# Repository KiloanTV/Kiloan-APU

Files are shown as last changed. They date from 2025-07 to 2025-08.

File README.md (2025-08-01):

<div>
  <h1 align="center">Kiloan APU V1</h1>

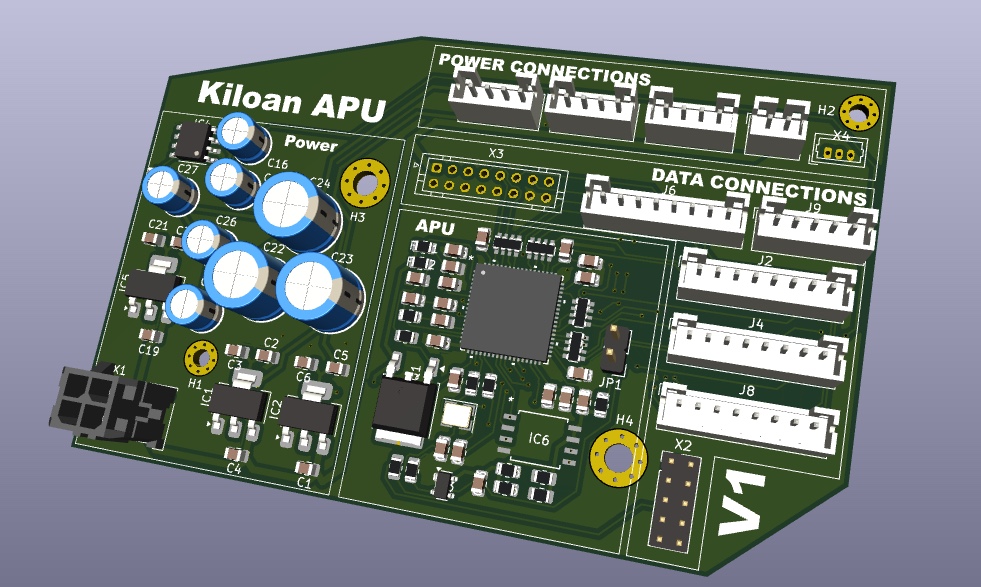
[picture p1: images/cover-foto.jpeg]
Kiloan-APU
  

  <p align="center">
  <a href="https://hackclub.com/highway">
    
  </a>
  </p>
  <h1></h1>
  <p align="center">
    The mainboard for a custom digital mixing console!
  </p>
</div>

<sub align="center">This work is licensed under the
[MIT License](https://mit-license.org).
</sub>

## Table of Contents

- [About](#about)
- [Pictures](#pictures)
- [Bill of Materials](#bill-of-materials)

# About

I've always wanted my own digital mixing console, but those things are just too expensive for teenagers. That's why I want to build my own! This is the mainboard, to which additional PCB boards will later be attached. They provide inputs/outputs (balanced XLR, of course), are responsible for the controls, and serve as a USB audio interface. This is the first step in this extensive project!

# Pictures

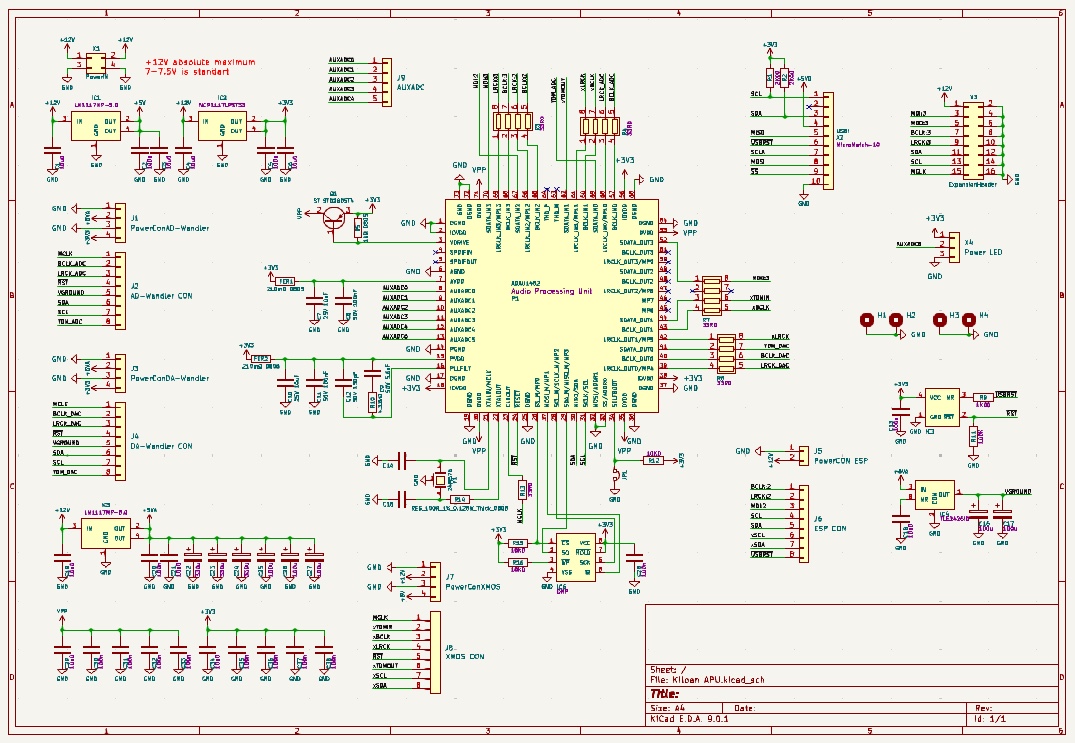
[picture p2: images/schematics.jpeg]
schematics


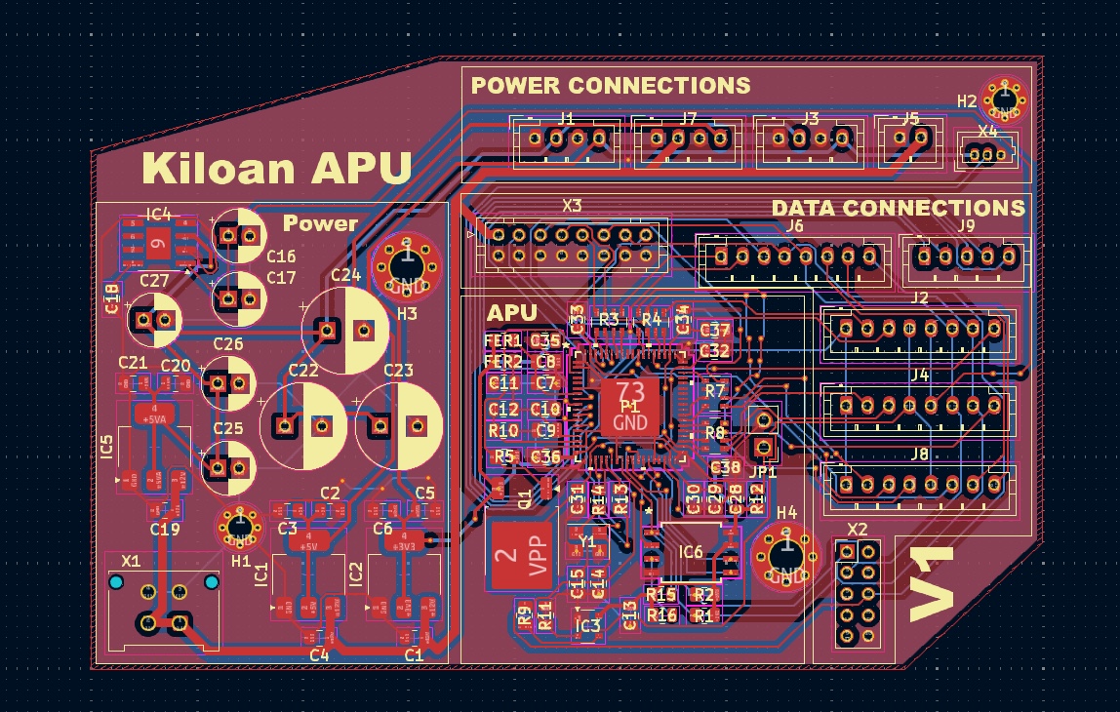
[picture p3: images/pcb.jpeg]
pcb


# Bill of Materials

|Reference |Value |Description |Qty|LCSC |Price|FIELD7 |
|---|---|---|---|---|-----|---|
|C1 |25V 10u0 | |1  |C391262 | | |
|C2,C5,C13,C20,C28,C30,C31,C32,C33,C35,C36,C37,C38|CAP_100n_50V_X7R_0805 | |13 |C3018562 | | |
|C3,C4,C6,C18,C19,C21,C29,C34 |CAP_10u0_25V_X5R_0805 | |8  |C391262 | | |
|C7,C10 |25V 10uF |25V 10uF X5R ±20% 0805 Multilayer Ceramic Capacitors MLCC - SMD/SMT ROHS |2  |C391262 | | |
|C8,C11 |50V 100nF |50V 100nF X7R ±10% 0805 Multilayer Ceramic Capacitors MLCC - SMD/SMT ROHS |2  |C3018562 | | |
|C9 |50V 5.6nF |50V 5.6nF X7R ±10% 0805 Multilayer Ceramic Capacitors MLCC - SMD/SMT ROHS |1  |C113862 | | |
|C12 |50V 150pF |50V 150pF C0G ±5% 0805 Multilayer Ceramic Capacitors MLCC - SMD/SMT ROHS |1  |C2168780 | | |
|C14,C15 |50V 12pF | |2  |C2168859 | | |
|C16,C17,C25,C26,C27 |CAP_100u_20%_25V_ALUM_RADIAL | |5  |C108360,C136287| | |
|C22,C23,C24 |330u_20%_25V_ALUM_RADIAL | |3  |C47344178 | | |
|FER1,FER2 |210mΩ 0805 |210mΩ ±25% 600Ω@100MHz 0805 Ferrite Beads ROHS |2  |C85837 | | |
|IC1,IC5 |IC_LM1117MP-5.0 | |2  |C131933 | | |
|IC2 |IC_NCP1117LPST33 | |1  |C146799 | | |
|IC3 |IC_ADM811TARTZ | |1  |C462205 | | |
|IC4 |IC_TLE2426ID | |1  |C59459 | | |
|IC6 |IC_25AA1024 | |1  |C2653525 | | |
|J1 |PowerConAD-Wandler |Generic connector, single row, 01x04, script generated (kicad-library-utils/schlib/autogen/connector/) |1  |C131334 | | |
|J2 |AD-Wandler CON |Generic connector, single row, 01x08, script generated (kicad-library-utils/schlib/autogen/connector/) |1  |C157974 | | |
|J3 |PowerConDA-Wandler |Generic connector, single row, 01x04, script generated (kicad-library-utils/schlib/autogen/connector/) |1  |C131334 | | |
|J4 |DA-Wandler CON |Generic connector, single row, 01x08, script generated (kicad-library-utils/schlib/autogen/connector/) |1  |C157974 | | |
|J5 |PowerCON ESP |Generic connector, single row, 01x02, script generated (kicad-library-utils/schlib/autogen/connector/) |1  |C131337 | | |
|J6 |ESP CON |Generic connector, single row, 01x08, script generated (kicad-library-utils/schlib/autogen/connector/) |1  |C157974 | | |
|J7 |PowerConXMOS |Generic connector, single row, 01x04, script generated (kicad-library-utils/schlib/autogen/connector/) |1  |C131334 | | |
|J8 |XMOS CON |Generic connector, single row, 01x08, script generated (kicad-library-utils/schlib/autogen/connector/) |1  |C157974 | | |
|J9 |AUXADC |Generic connector, single row, 01x05, script generated (kicad-library-utils/schlib/autogen/connector/) |1  |C157993 | | |
|JP1 |CON_JUMPER | |1  |C492401 | | |
|P1 |ADAU1452 |Audio Processing Unit |1  |C462188 | | |
|Q1 |ST STD2805T4 |PNP 60V 5A 150MHz 15W |1  |C672201 | | |
|R1,R2 |RES_2K00_1%_0.125W_Thick_0805| |2  |C114572 | | |
|R3,R4,R7,R8 |33R0_5%_4x0603 | |4  |C872331 | | |
|R5 |1kΩ 0805 |125mW Thick Film Resistor 150V ±100ppm/℃ ±1% 1kΩ 0805 Chip Resistor - Surface Mount ROHS |1  |C95781 | | |
|R9 |RES_1K00_1%_0.125W_Thick_0805| |1  |C95781 | | |
|R10 |4.32kΩ |125mW Thick Film Resistor 150V ±100ppm/℃ ±1% 4.32kΩ 0805 Chip Resistor - Surface Mount ROHS |1  |C483139 | | |
|R11 |RES_100K_1%_0.125W_Thick_0805| |1  |C96346 | | |
|R12,R15,R16 |RES_10K0_1%_0.125W_Thick_0805| |3  |C84376 | | |
|R13 |RES_33R0_1%_0.125W_Thick_0805| |1  |C126353 | | |
|R14 |RES_100R_1%_0.125W_Thick_0805| |1  |C105577 | | |
|X1 |PowerIN |2x2P 4P Micro-Fit(MX 3.0) Tin 3mm 2 -40℃~+105℃ 8.5A 2 3mm Brass Through Hole Through Hole,P=3mm Wire To Board Connector ROHS|1  |C277721 | | |
|X2 |USBi | |1  |C18723067 | | |
|X3 |ExpansionHeader | |1  |C3324391 | | |
|X4 |Power LED |Generic connector, single row, 01x03, script generated (kicad-library-utils/schlib/autogen/connector/) |1  |C122442 | | |
|Y1 |24M576 | |1  |C6040680 | | |
| | | | | | |Quote from LCSC: $27,07|
| | | | | | |Quote from JLCPCB: 4.17 USD|
| | | | | | |Quote Total: 31.24 USD|

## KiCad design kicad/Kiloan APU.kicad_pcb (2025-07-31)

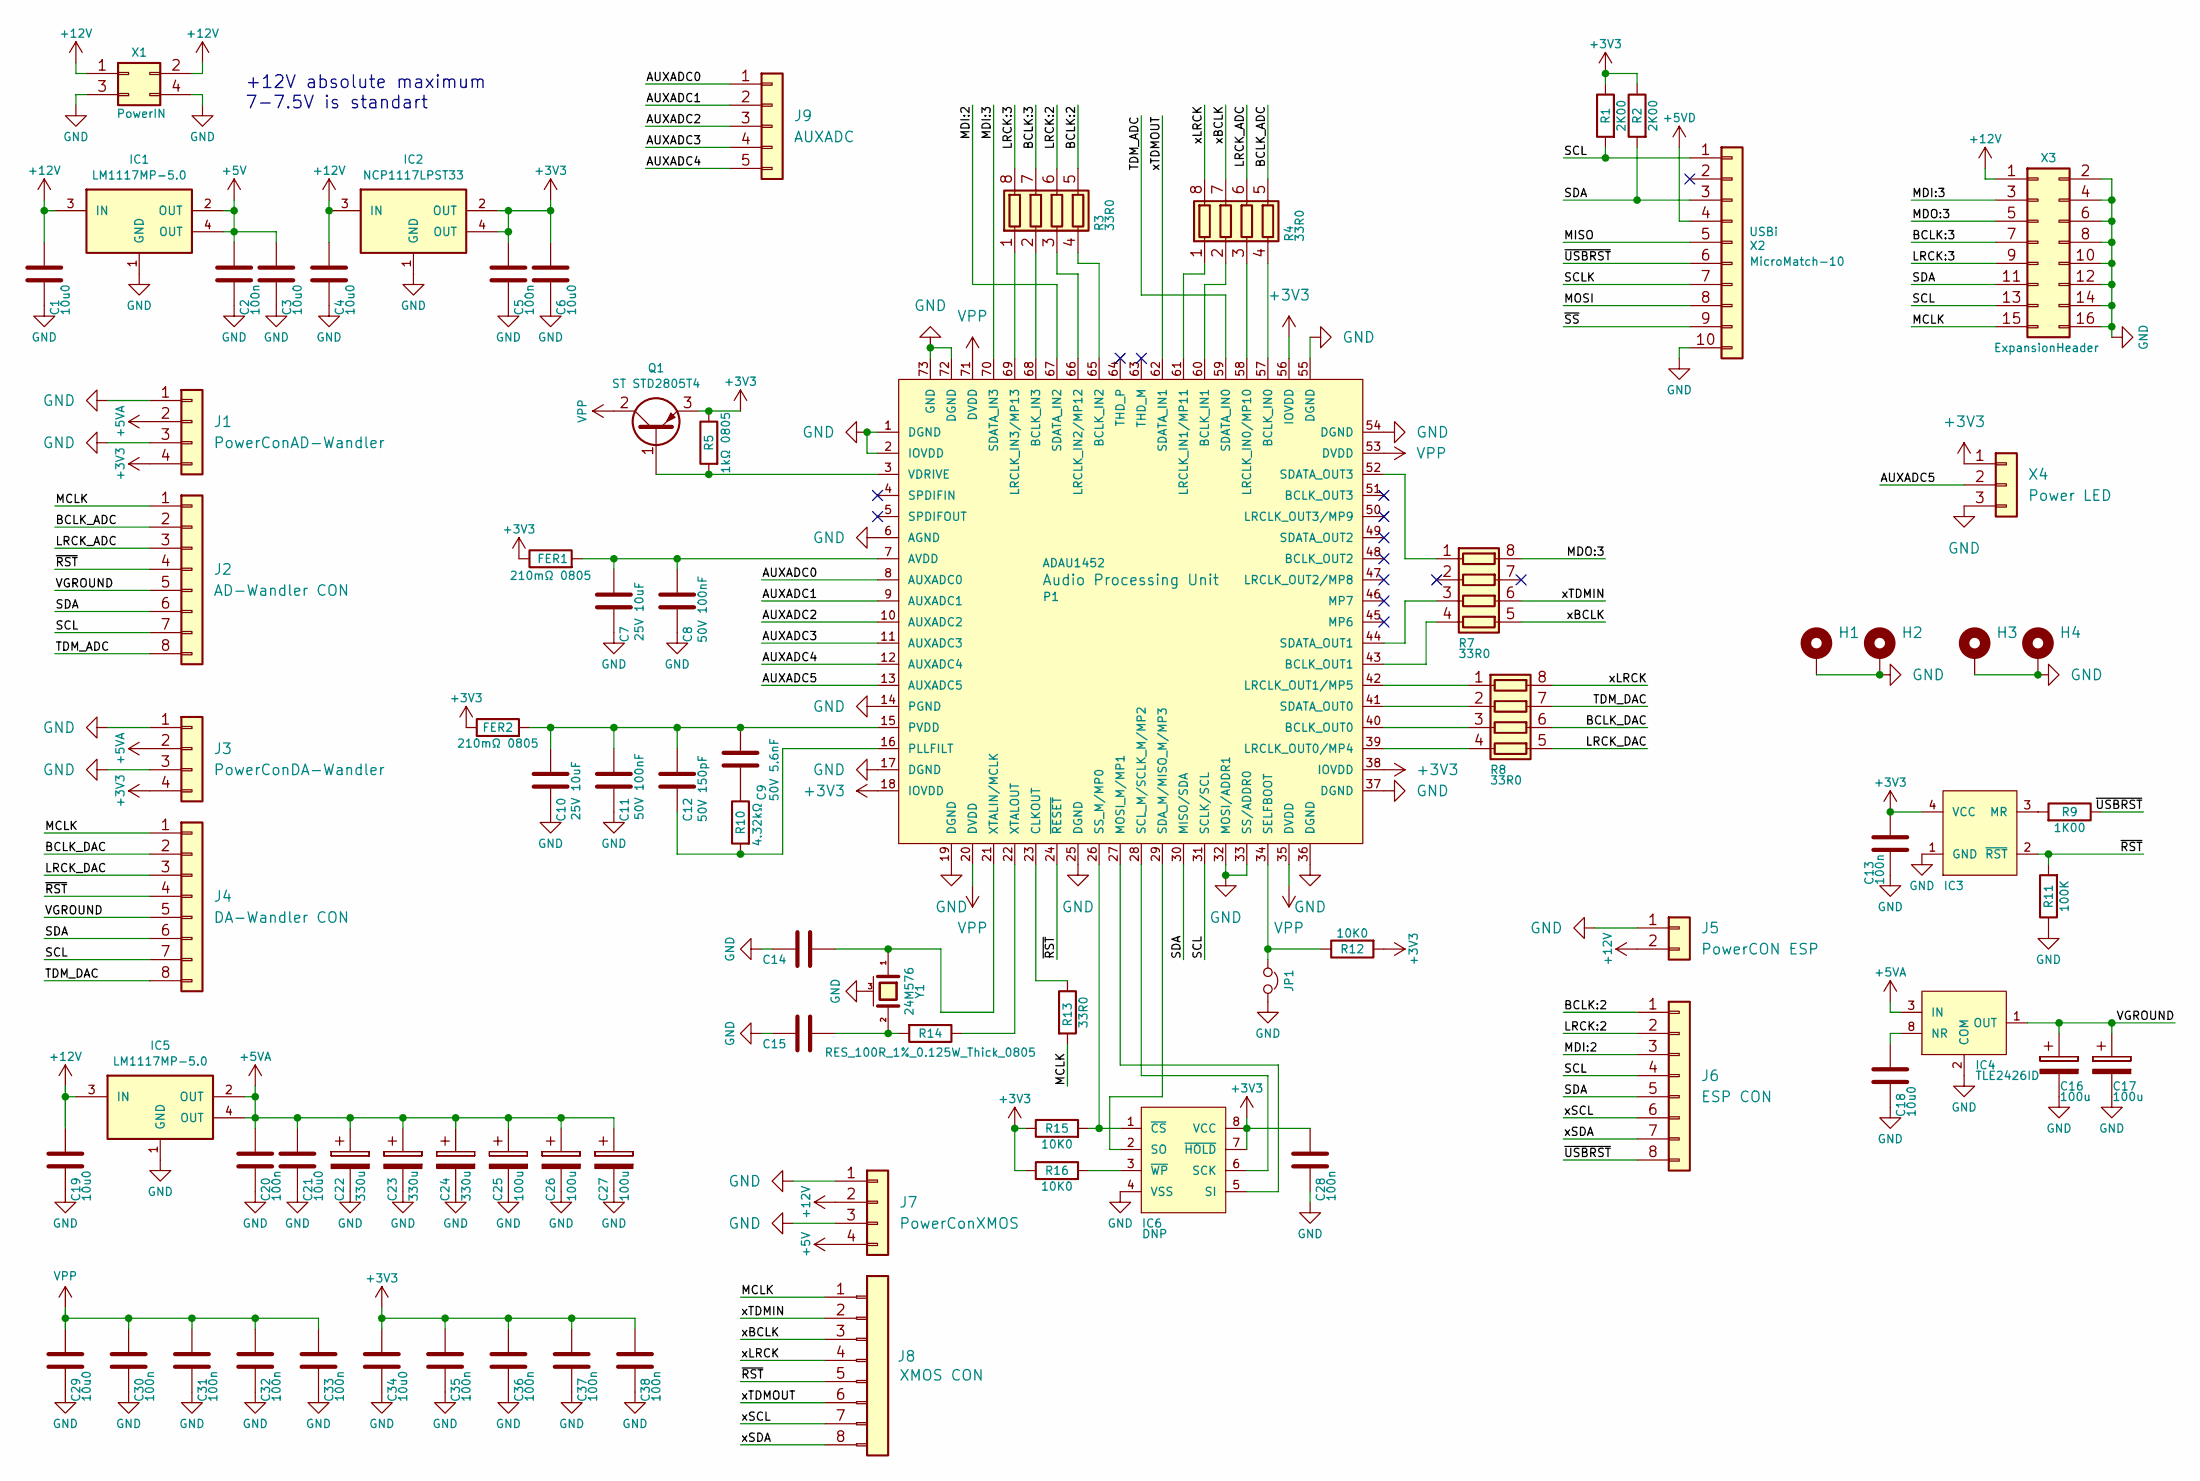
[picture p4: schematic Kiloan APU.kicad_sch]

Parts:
C1: 25V 10u0; C_0805_2012Metric; LCSC C391262
C2, C5, C13, C20, C28, C30, C31, C32, C33, C35, C36, C37, C38: CAP_100n_50V_X7R_0805; C_0805_2012Metric; LCSC C3018562
C3, C4, C6, C18, C19, C21, C29, C34: CAP_10u0_25V_X5R_0805; C_0805_2012Metric; LCSC C391262
C7, C10: 25V 10uF; C_0805_2012Metric; Part Number GRM21BR61E106MA73L; LCSC C391262
C8, C11: 50V 100nF; C_0805_2012Metric; Part Number C0805C104K5RACTU; LCSC C3018562
C9: 50V 5.6nF; C_0805_2012Metric; Part Number CC0805KRX7R9BB562; LCSC C113862
C12: 50V 150pF; C_0805_2012Metric; Part Number C0805C151J5GACTU; LCSC C2168780
C14, C15: 50V 12pF; C_0805_2012Metric; Part Number C0805C220J5GACTU; LCSC C2168859
C16, C17: CAP_100u_20%_25V_ALUM_RADIAL; CP_Radial_D5.0mm_P2.00mm; LCSC C136287
C22, C23, C24: 330u_20%_25V_ALUM_RADIAL; CP_Radial_D8.0mm_P3.50mm; LCSC C47344178
C25, C26, C27: CAP_100u_20%_25V_ALUM_RADIAL; CP_Radial_D5.0mm_P2.00mm; LCSC C108360
FER1, FER2: 210mΩ 0805; R_0805_2012Metric; Part Number BLM21AG601SN1D; LCSC C85837
H1, H2: MountingHole_Pad; MountingHole_2.2mm_M2_Pad_Via
H3, H4: MountingHole_Pad; MountingHole_3.2mm_M3_Pad_Via
IC1, IC5: IC_LM1117MP-5.0; SOT-223; LCSC C131933
IC2: IC_NCP1117LPST33; SOT-223; LCSC C146799
IC3: IC_ADM811TARTZ; SOT-143; Part Number ADM811TARTZ-REEL; LCSC C462205
IC4: IC_TLE2426ID; SOIC-8-1EP_3.9x4.9mm_P1.27mm_EP2.29x3mm; LCSC C59459
IC6: IC_25AA1024; SOIJ8-M_MC_MCH; LCSC C2653525
J1: PowerConAD-Wandler; JST_PH_B4B-PH-K_1x04_P2.00mm_Vertical; LCSC C131334
J2: AD-Wandler CON; JST_PH_B8B-PH-K_1x08_P2.00mm_Vertical; LCSC C157974
J3: PowerConDA-Wandler; JST_PH_B4B-PH-K_1x04_P2.00mm_Vertical; LCSC C131334
J4: DA-Wandler CON; JST_PH_B8B-PH-K_1x08_P2.00mm_Vertical; LCSC C157974
J5: PowerCON ESP; JST_PH_B2B-PH-K_1x02_P2.00mm_Vertical; LCSC C131337
J6: ESP CON; JST_PH_B8B-PH-K_1x08_P2.00mm_Vertical; LCSC C157974
J7: PowerConXMOS; JST_PH_B4B-PH-K_1x04_P2.00mm_Vertical; LCSC C131334
J8: XMOS CON; JST_PH_B8B-PH-K_1x08_P2.00mm_Vertical; LCSC C157974
J9: AUXADC; JST_PH_B5B-PH-K_1x05_P2.00mm_Vertical; LCSC C157993
JP1: CON_JUMPER; PinHeader_1x02_P2.54mm_Vertical; LCSC C492401
P1: ADAU1452; CP-72-6_ADI-M; Part Number ADAU1452WBCPZ-RL; LCSC C462188
Q1: ST STD2805T4; TO-252-2; Part Number STD2805T4; LCSC C672201
R1, R2: RES_2K00_1%_0.125W_Thick_0805; R_0805_2012Metric; LCSC C114572
R3, R4, R7, R8: 33R0_5%_4x0603; R_Array_Convex_4x0603; LCSC C872331
R5: 1kΩ 0805; R_0805_2012Metric; Part Number RC0805FR-071KL; LCSC C95781
R9: RES_1K00_1%_0.125W_Thick_0805; R_0805_2012Metric; LCSC C95781
R10: 4.32kΩ; R_0805_2012Metric; Part Number RC0805FR-074K32L; LCSC C483139
R11: RES_100K_1%_0.125W_Thick_0805; R_0805_2012Metric; LCSC C96346
R12, R15, R16: RES_10K0_1%_0.125W_Thick_0805; R_0805_2012Metric; LCSC C84376
R13: RES_33R0_1%_0.125W_Thick_0805; R_0805_2012Metric; LCSC C126353
R14: RES_100R_1%_0.125W_Thick_0805; R_0805_2012Metric; LCSC C105577
X1: PowerIN; Molex_Micro-Fit_3.0_43045-0412_2x02_P3.00mm_Vertical; Part Number 430450412; LCSC C277721
X2: USBi; PinHeader_2x05_P2.00mm_Vertical; LCSC C18723067
X3: ExpansionHeader; JST_PHD_B16B-PHDSS_2x08_P2.00mm_Vertical; LCSC C3324391
X4: Power LED; Molex_PicoBlade_53047-0310_1x03_P1.25mm_Vertical; LCSC C122442
Y1: 24M576; Crystal_SMD_3225-4Pin_3.2x2.5mm; LCSC C6040680

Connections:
+3V3: C5.1, C6.1, C13.1, C28.1, C34.1, C35.1, C36.1, C37.1, C38.1, FER1.1, FER2.1, IC2.2 (OUT), IC2.4 (OUT), IC3.4 (VCC), IC6.7 (~HOLD), IC6.8 (VCC), J1.4 (3V3), J3.4 (3V3), P1.18 (IOVDD), P1.38 (IOVDD), P1.56 (IOVDD), Q1.3 (E), R1.1, R2.1, R5.1, R12.2, R15.1, R16.1, X4.1
+5V: C2.1, C3.1, IC1.2 (OUT), IC1.4 (OUT), J7.4 (5V)
+5VA: C20.1, C21.1, C22.1, C23.1, C24.1, C25.1, C26.1, C27.1, IC4.3 (IN), IC5.2 (OUT), IC5.4 (OUT), J1.2 (5VA), J3.2 (5VA)
+5VD: X2.4
+12V: C1.1, C4.1, C19.1, IC1.3 (IN), IC2.3 (IN), IC5.3 (IN), J5.2 (12V), J7.2 (12V), X1.1, X1.2, X3.1
/AUXADC0: J9.1, P1.8 (AUXADC0)
/AUXADC1: J9.2, P1.9 (AUXADC1)
/AUXADC2: J9.3, P1.10 (AUXADC2)
/AUXADC3: J9.4, P1.11 (AUXADC3)
/AUXADC4: J9.5, P1.12 (AUXADC4)
/AUXADC5: P1.13 (AUXADC5), X4.2
/BCLK:2: J6.1 (BCLK), R3.5 (R4.2)
/BCLK:3: R3.7 (R2.2), X3.7
/BCLK_ADC: J2.2 (BCLK), R4.5 (R4.2)
/BCLK_DAC: J4.2 (BCLK), R8.6 (R3.2)
/LRCK:2: J6.2 (LRCK), R3.6 (R3.2)
/LRCK:3: R3.8 (R1.2), X3.9
/LRCK_ADC: J2.3 (LRCK), R4.6 (R3.2)
/LRCK_DAC: J4.3 (LRCK), R8.5 (R4.2)
/MCLK: J2.1 (MCLK), J4.1 (MCLK), J8.1 (MCLK), R13.2, X3.15
/MDI:2: J6.3 (SDATA), P1.67 (SDATA_IN2)
/MDI:3: P1.70 (SDATA_IN3), X3.3
/MDO:3: R7.8 (R1.2), X3.5
/MISO: X2.5
/MOSI: X2.8
/SCL: J2.7 (SCL), J4.7 (SCL), J6.4 (SCL1), P1.31 (SCLK/SCL), R1.2, X2.1, X3.13
/SCLK: X2.7
/SDA: J2.6 (SDA), J4.6 (SDA), J6.5 (SDA1), P1.30 (MISO/SDA), R2.2, X2.3, X3.11
/TDM_ADC: J2.8 (TDM), P1.59 (SDATA_IN0)
/TDM_DAC: J4.8 (TDM), R8.7 (R2.2)
/VGROUND: C16.1, C17.1, IC4.1 (OUT), J2.5 (VGROUND), J4.5 (VGROUND)
/xBCLK: J8.3 (XBCLK), R4.7 (R2.2), R7.5 (R4.2)
/xLRCK: J8.4 (XLRCK), R4.8 (R1.2), R8.8 (R1.2)
/xSCL: J6.6 (SCL2), J8.7 (SCL)
/xSDA: J6.7 (SDA2), J8.8 (SDA)
/xTDMIN: J8.2 (XTDMIN1), R7.6 (R3.2)
/xTDMOUT: J8.6 (XTDMOUT1), P1.62 (SDATA_IN1)
/~RST: IC3.2 (~RST), J2.4 (RST), J4.4 (RST), J8.5 (RST), P1.24 (~RESET), R11.2
/~SS: X2.9
/~USBRST: J6.8 (MRST), R9.1, X2.6
GND: C1.2, C2.2, C3.2, C4.2, C5.2, C6.2, C7.2, C8.2, C10.2, C11.2, C13.2, C14.2, C15.2, C16.2, C17.2, C18.2, C19.2, C20.2, C21.2, C22.2, C23.2, C24.2, C25.2, C26.2, C27.2, C28.2, C29.2, C30.2, C31.2, C32.2, C33.2, C34.2, C35.2, C36.2, C37.2, C38.2, H1.1, H2.1, H3.1, H4.1, IC1.1 (GND), IC2.1 (GND), IC3.1 (GND), IC4.2 (COM), IC5.1 (GND), IC6.4 (VSS), J1.1 (GND), J1.3 (GND), J3.1 (GND), J3.3 (GND), J5.1 (GND), J7.1 (GND), J7.3 (GND), JP1.2, P1.1 (DGND), P1.2 (IOVDD), P1.6 (AGND), P1.14 (PGND), P1.17 (DGND), P1.19 (DGND), P1.25 (DGND), P1.32 (MOSI/ADDR1), P1.33 (SS/ADDR0), P1.36 (DGND), P1.37 (DGND), P1.54 (DGND), P1.55 (DGND), P1.72 (DGND), P1.73 (GND), R11.1, X1.3, X1.4, X2.10, X3.2, X3.4, X3.6, X3.8, X3.10, X3.12, X3.14, X3.16, X4.3, Y1.3 (case)
unnamed: C9.2, R10.1
unnamed: C15.1, R14.2, Y1.2
unnamed: IC3.3 (MR), R9.2
unnamed: C18.1, IC4.8 (NR)
unnamed: IC6.6 (SCK), P1.28 (SCL_M/SCLK_M/MP2)
unnamed: IC6.5 (SI), P1.27 (MOSI_M/MP1)
unnamed: IC6.2 (SO), P1.29 (SDA_M/MISO_M/MP3)
unnamed: IC6.1 (~CS), P1.26 (SS_M/MP0), R15.2
unnamed: IC6.3 (~WP), R16.2
unnamed: C7.1, C8.1, FER1.2, P1.7 (AVDD)
unnamed: P1.57 (BCLK_IN0), R4.4 (R4.1)
unnamed: P1.60 (BCLK_IN1), R4.2 (R2.1)
unnamed: P1.65 (BCLK_IN2), R3.4 (R4.1)
unnamed: P1.68 (BCLK_IN3), R3.2 (R2.1)
unnamed: P1.40 (BCLK_OUT0), R8.3 (R3.1)
unnamed: P1.43 (BCLK_OUT1), R7.4 (R4.1)
unnamed: P1.23 (CLKOUT), R13.1
unnamed: P1.58 (LRCLK_IN0/MP10), R4.3 (R3.1)
unnamed: P1.61 (LRCLK_IN1/MP11), R4.1 (R1.1)
unnamed: P1.66 (LRCLK_IN2/MP12), R3.3 (R3.1)
unnamed: P1.69 (LRCLK_IN3/MP13), R3.1 (R1.1)
unnamed: P1.39 (LRCLK_OUT0/MP4), R8.4 (R4.1)
unnamed: P1.42 (LRCLK_OUT1/MP5), R8.1 (R1.1)
unnamed: C12.2, P1.16 (PLLFILT), R10.2
unnamed: C9.1, C10.1, C11.1, C12.1, FER2.2, P1.15 (PVDD)
unnamed: P1.41 (SDATA_OUT0), R8.2 (R2.1)
unnamed: P1.44 (SDATA_OUT1), R7.3 (R3.1)
unnamed: P1.52 (SDATA_OUT3), R7.1 (R1.1)
unnamed: JP1.1, P1.34 (SELFBOOT), R12.1
unnamed: P1.3 (VDRIVE), Q1.1 (B), R5.2
unnamed: C14.1, P1.21 (XTALIN/MCLK), Y1.1
unnamed: P1.22 (XTALOUT), R14.1
VPP: C29.1, C30.1, C31.1, C32.1, C33.1, P1.20 (DVDD), P1.35 (DVDD), P1.53 (DVDD), P1.71 (DVDD), Q1.2 (C)

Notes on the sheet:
+12V absolute maximum 7-7.5V is standart

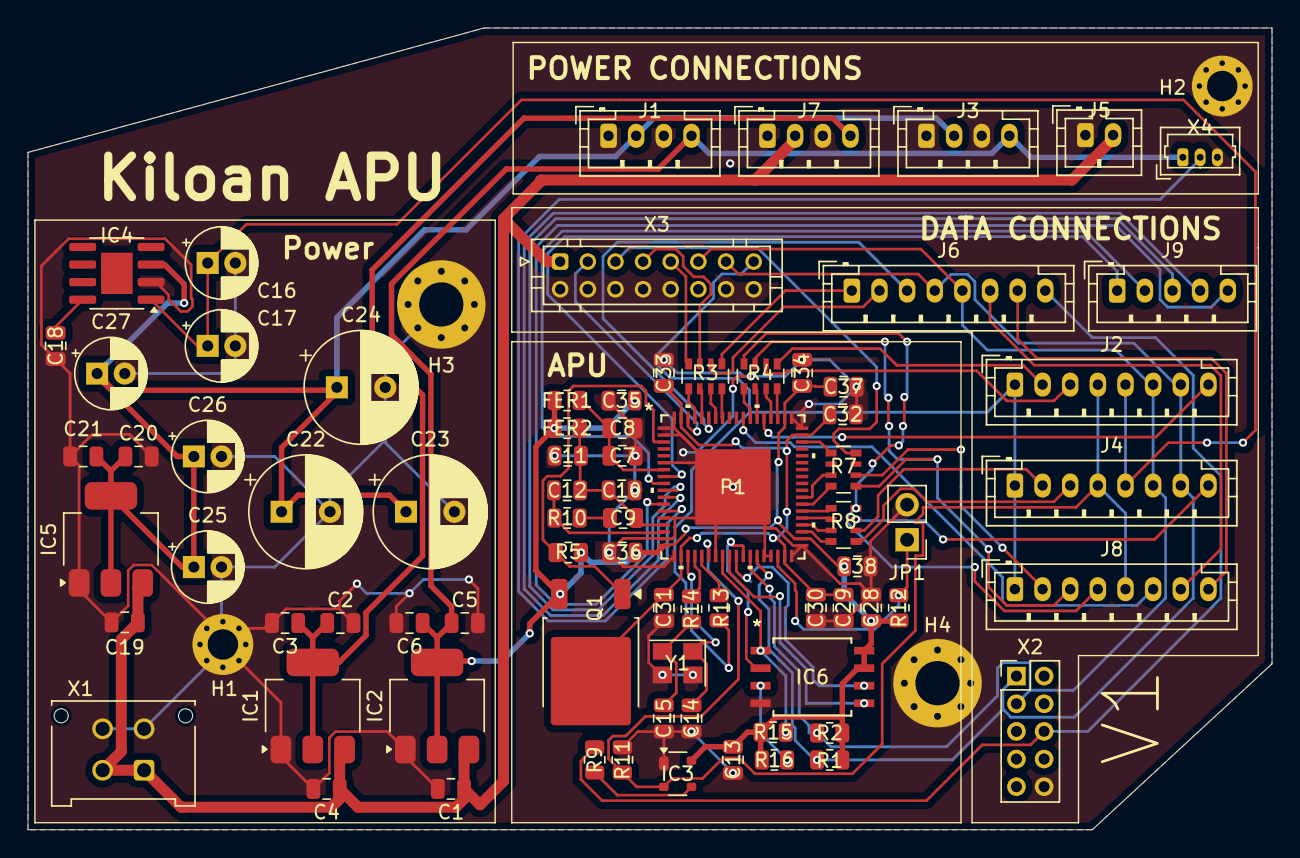
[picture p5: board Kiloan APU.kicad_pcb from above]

Board: 2 copper layers, 90.0 x 58.0 mm, 82 parts (0 on the bottom side), 69 nets.

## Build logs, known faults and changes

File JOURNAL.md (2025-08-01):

---
title: "Kiloan APU"
author: "Kian Lorenz"
description: "The mainboard for a custom digital mixing console."
created_at: "2025-07-30"
---

**Total time spent: 13hrs**

# June 30th - Schematics (7hrs)

I've had the idea of my own inexpensive DIY digital mixer in my head for a while. Now I've remembered it again, and I have two days left to design the mainboard. The whole thing is based on the ADAU1452, an audio DSP. This has several connectors for an analog-to-digital converter (8 channels), a digital-to-analog converter (also 8 channels), an ESP32 for controlling the audio tracks, and an XMOS chip for an 8-channel USB audio interface like the FreeDSP Aurora. The FreeDSP Aurora inspired me for this whole concept, and I learned a lot from this project. There's a power section to provide individual voltages for all the chips. The external PCB boards with the chips mentioned above all have two JST connectors to the mainboard, one for power and one for data transmission. I will develop these pcb boards when the mainboard is fully functional.

schematics

Each external PCB board (ADC/DAC converter, XMOS USB Audio, ESP32) has a power connector that supplies the required voltage. Each board also has a data connector for TDM8 connections and I2S/I2C connections to the ESP32.

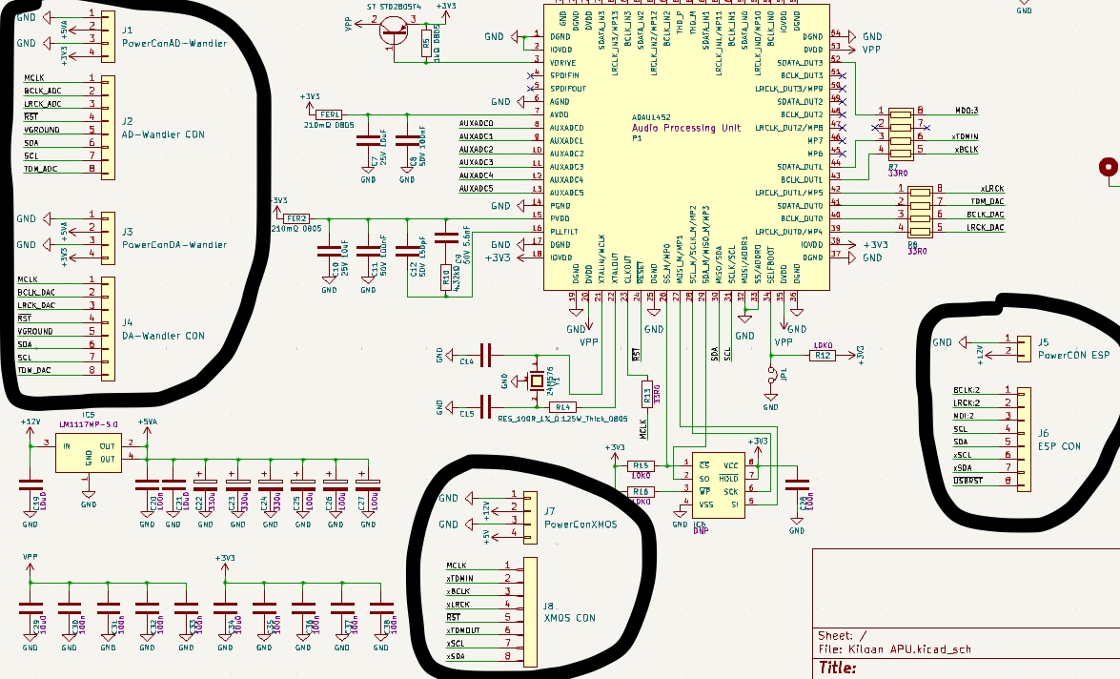
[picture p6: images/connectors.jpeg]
connectors


Five digital pins of the ADAU1452 chip are exposed for flexibility in use; the sixth pin is used for a power-on LED. The USBi header for programming the DSP chip is shown in green. I also adopted the standard expansion header from FreeDSP (shown in red) to use their expansion boards before designing my own.

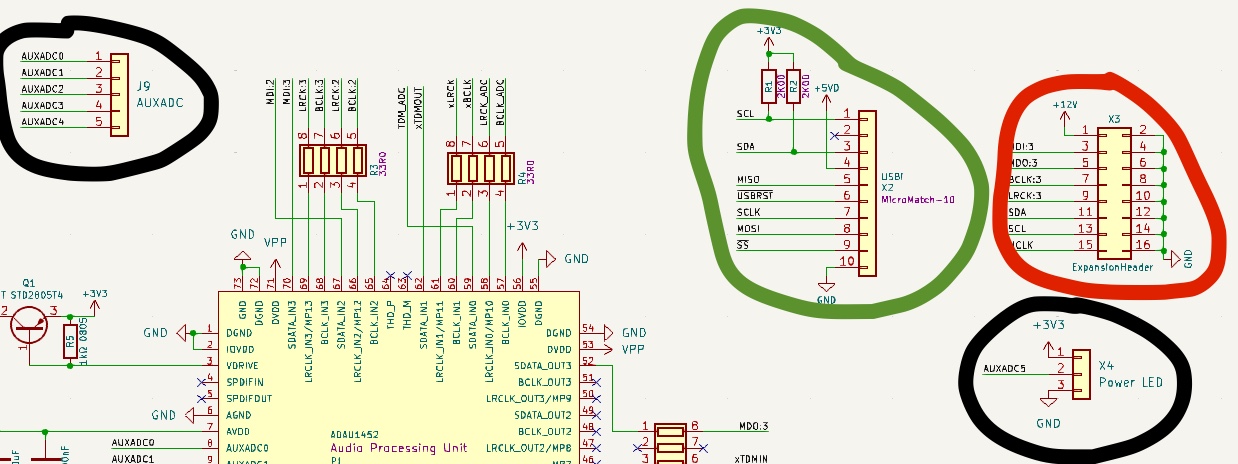
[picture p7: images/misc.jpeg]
misc


# June 31th - Layout and Routing (6hrs)

Today I placed the components on the PCB and routed them. I have no idea if everything will work, as this is my third PCB. I created individual sections to keep everything organized and added mounting solutions to secure the PCB. I think it is quite nice!

pcb

It was really complicated for me to create the traces around the DSP chips and to get all the data connections correct and, above all, AWAY from the chip to the connectors!

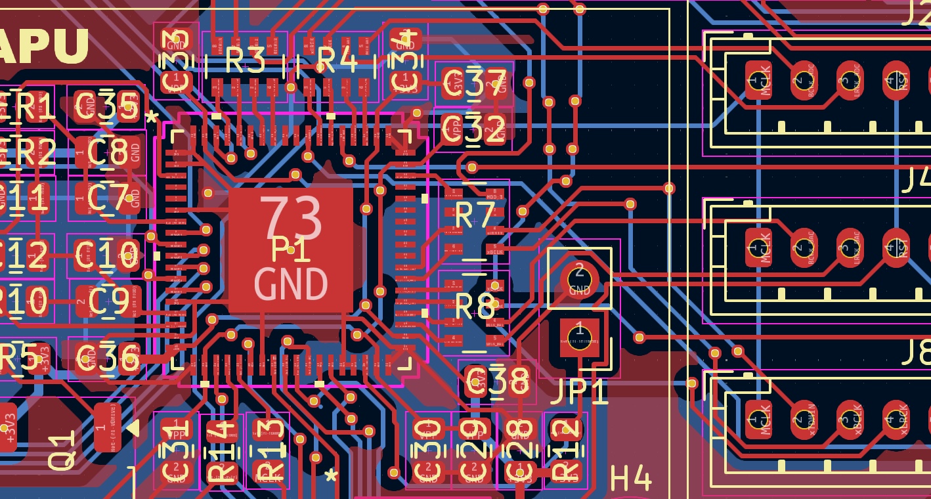
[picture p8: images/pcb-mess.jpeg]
pcb-mess


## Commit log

2025-07-31 add log and files from 30&31
    [Kiloan APU.kicad_pcb, Kiloan APU.kicad_sch, Kiloan-APU-LCSC.csv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]
2025-07-31 Update and rename Kiloan-APU-LCSC.csv to BOM.csv
    [BOM.csv]
